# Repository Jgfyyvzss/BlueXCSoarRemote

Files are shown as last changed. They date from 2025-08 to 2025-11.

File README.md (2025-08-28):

# BlueXCSoarRemote
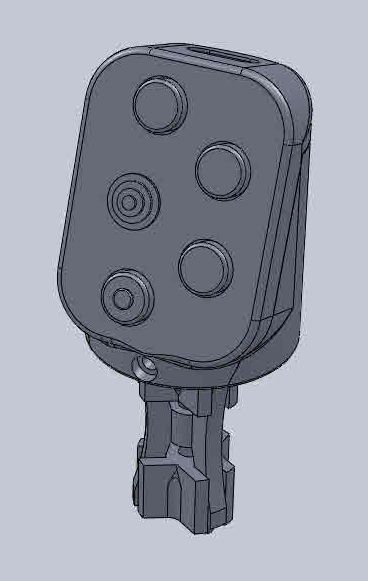
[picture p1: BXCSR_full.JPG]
BlueXCSoarRemote model Cad Model

## Features
A compact Bluetooth remote stick for XCSoar based around an ESP32-C3 Supermini.
* Entirely 3D printed. No need for machined front panels or joystick adapters.
* Sends keystrokes via Bluetooth so only 5V power needs to be supplied to the Remote.
* 5-way navigation joystick
* three top buttons around the joystick
* PTT button at the bottom left.
* On the front of the stick is provision for another two buttons that can be either connected to the remote board or wired direct to other instruments.
* Software is updatable via WiFi or the USB-C port is easily accessible from the top of the stick without any disassembly.

In my setup I use the lower button wired direct to an S100 for Thermal/STF mode switching. The upper button is reserved for future use if I need it.

The keys respond to Click, Double-Click and Long-Press separately, enabling a large number of keystrokes to be sent to XCSoar. In the default cnfiguration the top two buttons use the different clicks, the lower left button is ESC on all three modes.

The head is designed to sit on the top of an existing grip. I don't really like the "ergonomic" control grips, preferring a simple round firm foam grip. I designed this specifically to fit a Galsflugel 19mm dia stick with an ESI Extra Chunky MTB grip on it, but it will likely work OK with many other simple grips.

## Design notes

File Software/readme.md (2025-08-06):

## Key features:
* OTA updates of both Firmware and Keymap file can be done direct from a device to the Remote. The Remote creates an Access Point.
* Keymap can be updated without any change to Firmware. Easily change your button mapping at any time.
* All buttons can have separate actions for Click, Double-Click and Long-Press. Possibility of 24 different keystrokes being sent (only 12 unique keystrokes can be sent at this time).

Currently the following keystrokes can be sent:<br/>
ESC - KEY_ESC<br/>
RETURN - KEY_RETURN<br/>
F1 - KEY_F1<br/>
F2 - KEY_F2<br/>
...<br/>
F10 - KEY_F10<br/>

When the remote first starts (power on) it checks to see if the TopLeft button is being held down. If it is it goes into OTA update mode and starts the Access Point and webserver.<br/>
You will find a WiFi network called BLUEXCREM, password 12345678<br/>
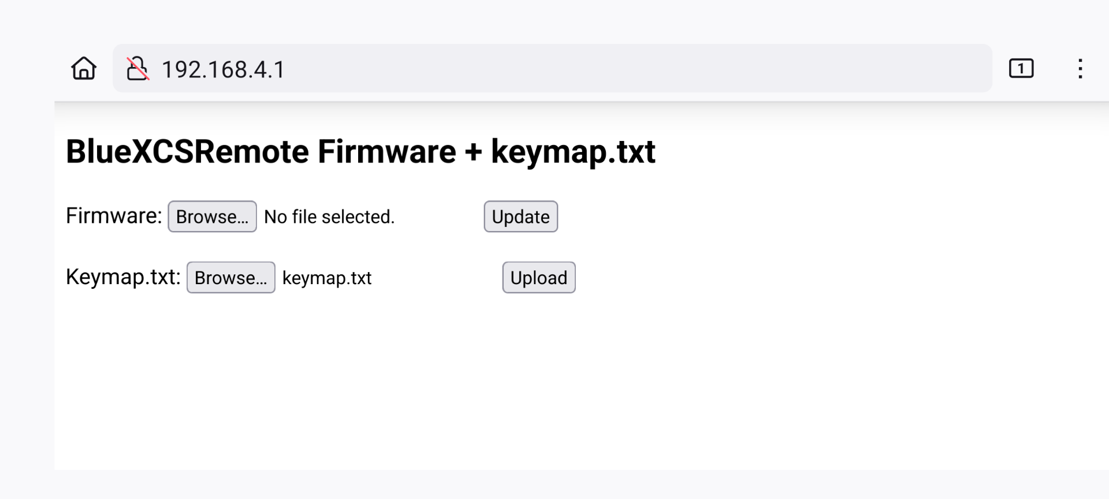
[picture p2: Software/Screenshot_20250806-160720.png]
Once connected to that network you can browse to http://192.168.4.1 (make sure your browser isn't tying to force an https connection) and a page will appear allowing you to select a Firmware ( .bin) or keymap.txt file to /

The keymap.txt file is a simple text file that looks like:<br/>
 \# Click,DoubleClick,LongPress<br/>
Top,KEY_F1,KEY_F3,KEY_F8<br/>
TopRight,KEY_F4,KEY_F5,KEY_F6<br/>
BotRight,KEY_ESC,KEY_ESC,KEY_ESC<br/>
Left,KEY_LEFT_ARROW,,<br/>
Right,KEY_RIGHT_ARROW,,<br/>
Up,KEY_UP_ARROW,,<br/>
Down,KEY_DOWN_ARROW,,<br/>
Centre_Click,KEY_RETURN,,KEY_ESC<br/>

Displaying it as a table makes it easier to understand:<br/>
|# |Click|DoubleClick|LongPress|
|--|-----|---|---|
|Top|KEY_F1|KEY_F3|KEY_F8|
|TopRight|KEY_F4|KEY_F5|KEY_F6|
|BotRight|KEY_ESC|KEY_ESC|KEY_ESC|
|Left|KEY_LEFT_ARROW|||
|Right|KEY_RIGHT_ARROW|||
|Up|KEY_UP_ARROW|||
|Down|KEY_DOWN_ARROW|||
|Centre_Click|KEY_RETURN||KEY_ESC|

The first column is the button name or position.<br/>
Blank cells are ignored.<br/>
Only those keystrokes listed above can be included.<br/>

### Requirements for succesful compilation of the firmware
* Arduino IDE 2+ (created in 2.3.6)
* Arduino IDE esp32 board version 2.0.11. More recent versions will fail to run the BleKeyboard.
* [BleKeyboard library](https://github.com/T-vK/ESP32-BLE-Keyboard) See Note 1.
* [Button2 library](https://github.com/LennartHennigs/Button2)

Note 1: BleKeyboard.cpp has to be modified.<br/>
In your Libraries folder (File | Preferences - Sketchbook Folder) open BleKeyboard.cpp in a plain text editor and find the line:<br/>
pSecurity->setAuthenticationMode(ESP_LE_AUTH_REQ_SC_MITM_BOND);<br/>
Replace this with<br/>
pSecurity->setAuthenticationMode(ESP_LE_AUTH_BOND);<br/>

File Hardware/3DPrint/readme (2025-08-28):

Design of the control head was done in Solidworks 2010.
Slicing via Ultimaker Cura 5.
I printed using a Cocoon Create Touch (Wanhao Duplicator i3 plus)
The screw to retain the faceplate was just scavenged from surplus consumer electronics. Not too critical, just an approximately 2.5mm dia self tapping type screw.

I have included the STL files here for a one-stop-shop, but the full file set will be available at thingiverse.
The front panel should be printed face down with support. The more support the better, but it's a balance between finish quality and being able to remove the support.
The main body is printed standing upright. I've filled the front holes and USB access with a thin web that can easily be cut out if needed to avoid messing with support.
An M3 x 40 socket head screw, nut and washer is used to tighten the Star Plug. Print two Expanders and three StarSingle's.
50% fill seems to produce a good sturdy print, but up to you to experiment.

Retention of the main PCB is by clamping between the two body components, you may need to do some hand finishing of the board to get it to fit and locate correctly.
The front PCB is retained by melting the vertical ribs in a few places. Use an old soldering iron tip or heat up a bit of wire etc. 
Don't go overboard, if you need to remove the PCB you'll need to cut off the melted sections and you'll want to be able to melt new areas when you replace it.

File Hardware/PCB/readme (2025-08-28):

There are two PCB's. BlueXCRemote carrying the Esp32 and main buttons, and FrontButtons carrying the two secondary buttons on the front of the stick.

PCB design was done in Kicad 9.
PCB production was by JLCPCB who accepted the Gerbers with no alterations required.

The front buttons PCB in the first version only has one ground connection. 
This could present a problem if you want to use one button via the ESP32 and the other to control another instrument directly if the other instrument doesn't use battery negative for it's signal ground. Possibly unlikely, but I'll add a second ground pad just in case.

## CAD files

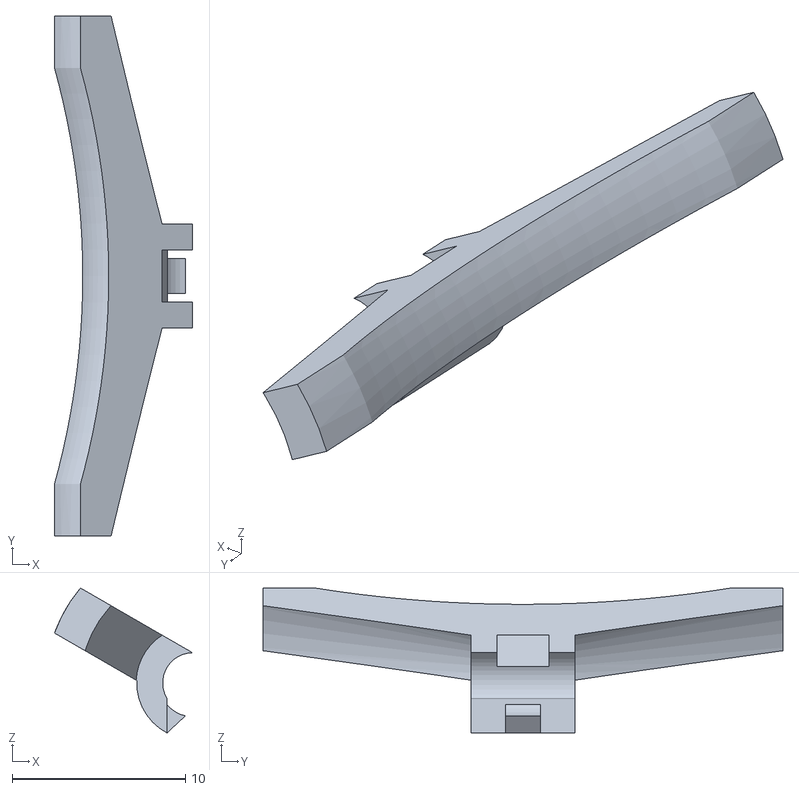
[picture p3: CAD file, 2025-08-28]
Hardware/3DPrint/StarSingle.STL
7.97 x 30.0 x 8.37

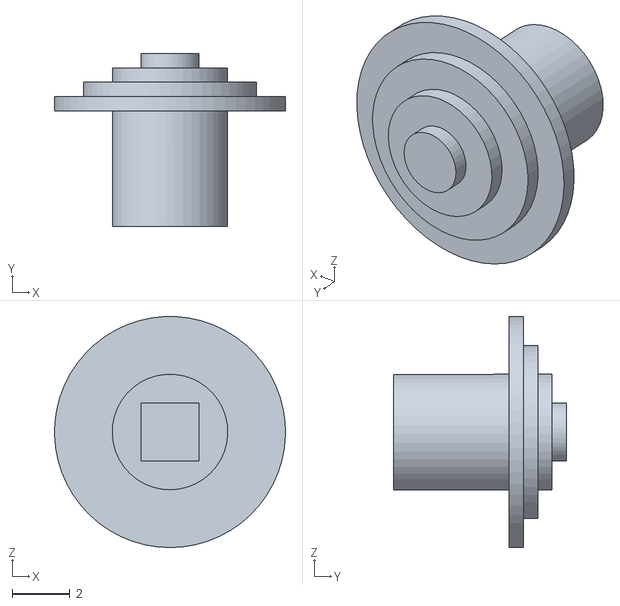
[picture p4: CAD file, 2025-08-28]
Hardware/3DPrint/Joystick.STL
8.00 x 6.00 x 8.00

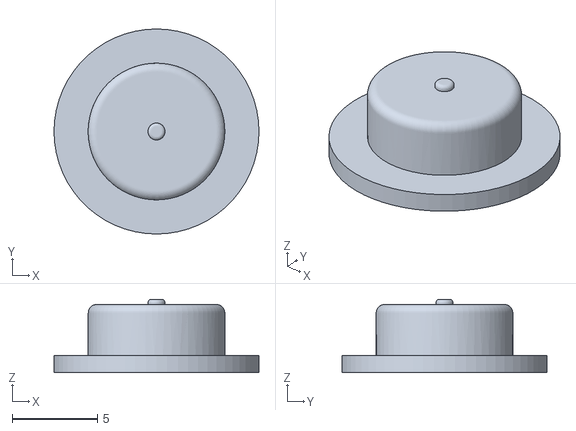
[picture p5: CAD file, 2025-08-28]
Hardware/3DPrint/ButtonR.STL
12.0 x 12.0 x 4.30

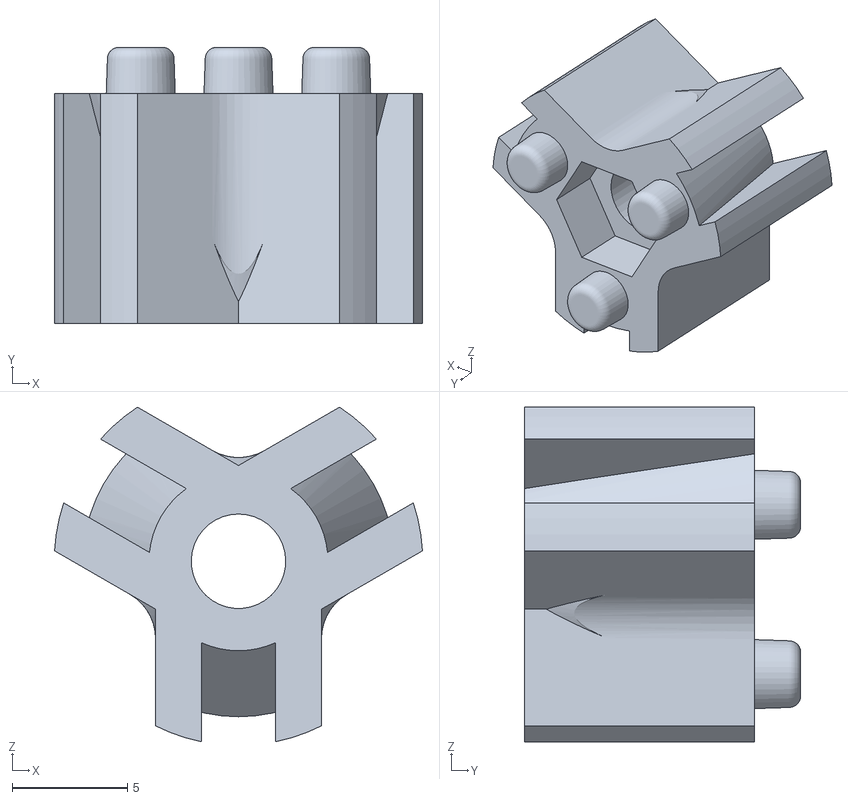
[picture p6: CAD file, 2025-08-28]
Hardware/3DPrint/StarPlugExpander.STL
16.0 x 12.0 x 14.5

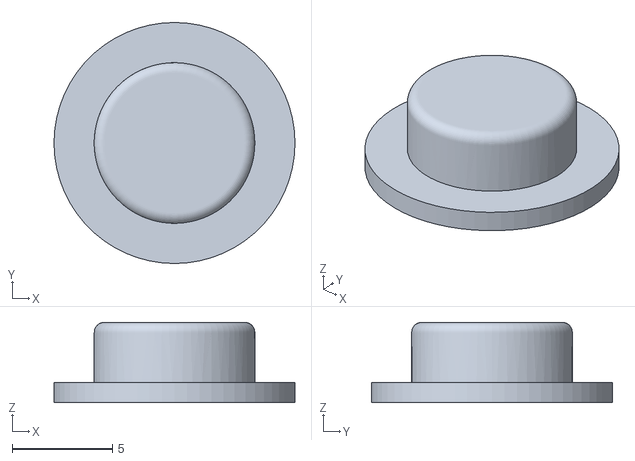
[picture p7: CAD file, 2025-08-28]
Hardware/3DPrint/Button.STL
12.0 x 12.0 x 4.00

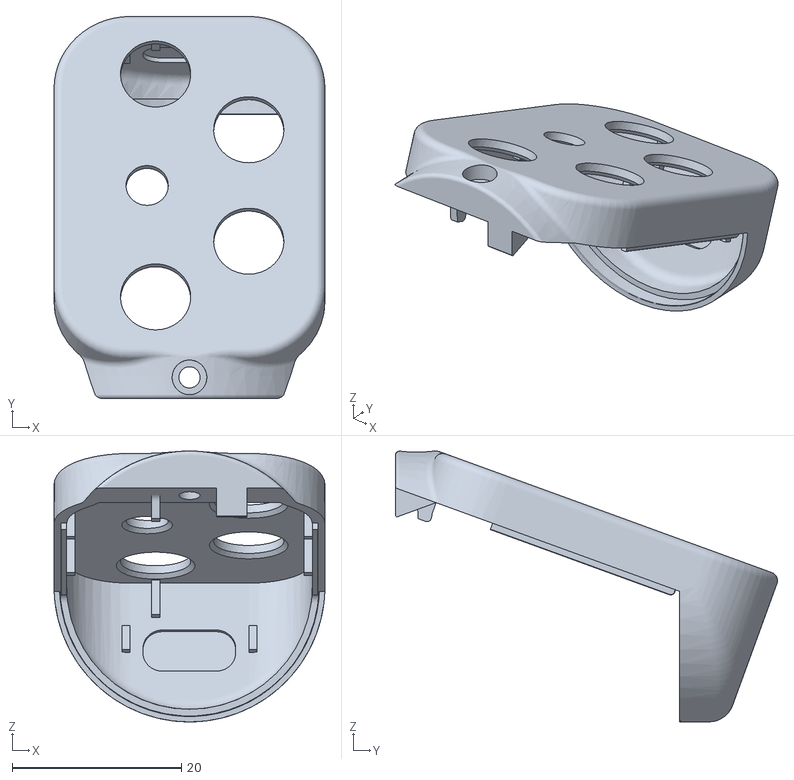
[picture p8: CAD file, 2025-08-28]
Hardware/3DPrint/BR_Body FR.STL
32.0 x 45.1 x 32.0

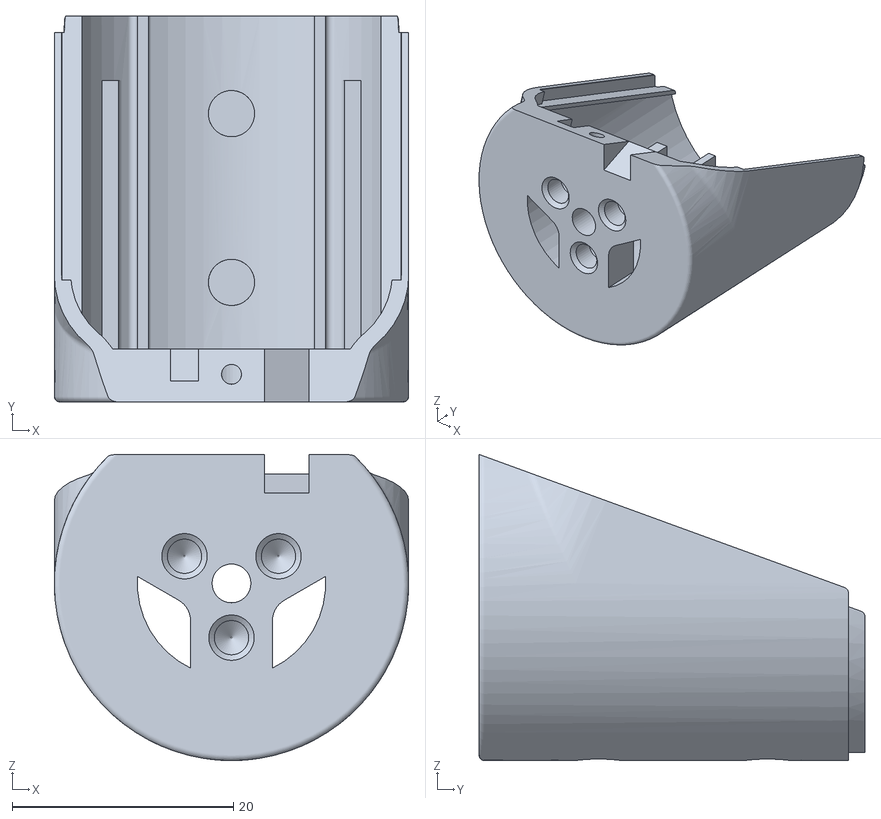
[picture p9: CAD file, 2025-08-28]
Hardware/3DPrint/BR_Body.STL
32.0 x 34.9 x 27.6

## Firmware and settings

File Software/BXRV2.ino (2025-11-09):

// SSID & Pwd at void setupOTA() IP defaults 192.168.4.1
//IO pins defined below #includes
#include <Arduino.h>
#include <Hardware.h>
#include <BleKeyboard.h>
#include <Button2.h>
#include <WiFi.h>
#include <WebServer.h>
#include <Update.h>
#include <LittleFS.h>

#define NUM_BUTTONS 10

BleKeyboard bleKeyboard("BXRKeyboard", "ESP32", 100);
Button2 buttons[NUM_BUTTONS];
// If not using external buttons to XCSoar, decrease count, remove pins, modify data/keymap.txt
// Do not use IO9. Avoid IO2, IO8
// USB on top IO 5, 8, 21, 2, 4, 3, 0, 1, 10, 20
// USB on bottom IO 0, 3, 10, 4, 6, 20, 5, 7, 
const uint8_t buttonPins[NUM_BUTTONS] = {5, 8, 21, 0, 3, 4, 2, 1, 20, 10};

// Button mapping reference:
// Index 0 - Top          = IO pin 5 
// Index 1 - TopRight     = IO pin 8  
// Index 2 - BotRight     = IO pin 21
// Index 3 - Left         = IO pin 0 
// Index 4 - Right        = IO pin 3
// Index 5 - Up           = IO pin 4
// Index 6 - Down         = IO pin 2
// Index 7 - Centre_Click = IO pin 1
// Index 8 - FrTop        = IO pin 20
// Index 9 - FrBot        = IO pin 10 

void handleClick(Button2& btn);
void handleDoubleClick(Button2& btn);
void handleLongClick(Button2& btn);
void loadKeymap();
void sendKey(const String& keyStr);
uint8_t lookupKeyCode(const String& name);

// OTA server
WebServer server(80);
bool otaEnabled = false;

//file upload
File keymapUploadFile;
String uploadBuffer = "";

// OTA HTML Form
void handleRoot() {
  String html = "<!DOCTYPE html>";
  html += "<html><head><title>ESP32C3 Keyboard OTA</title>";
  html += "<style>";
  html += "body { font-family: Arial; margin: 40px; background: #f0f0f0; }";
  html += ".container { background: white; padding: 20px; border-radius: 8px; max-width: 600px; }";
  html += ".upload-section { margin: 20px 0; padding: 15px; border: 1px solid #ddd; border-radius: 4px; }";
  html += "input[type=file] { margin: 10px 0; }";
  html += "button { background: #007cba; color: white; padding: 10px 20px; border: none; border-radius: 4px; cursor: pointer; }";
  html += "button:hover { background: #005a87; }";
  html += "textarea { width: 100%; height: 200px; font-family: monospace; }";
  html += "</style></head><body>";
  html += "<div class=\"container\">";
  html += "<h1>ESP32C3 Keyboard OTA Update</h1>";
  html += "<div class=\"upload-section\">";
  html += "<h3>Firmware Update</h3>";
  html += "<form method='POST' action='/update' enctype='multipart/form-data'>";
  html += "<input type='file' name='update' accept='.bin'>";
  html += "<button type='submit'>Update Firmware</button>";
  html += "</form></div>";
  html += "<div class=\"upload-section\">";
  html += "<h3>Keymap Management</h3>";
  html += "<button onclick=\"downloadKeymap()\">Download Current Keymap</button>";
  html += "<form method='POST' action='/keymap' enctype='multipart/form-data' style=\"margin-top:10px;\">";
  html += "<input type='file' name='keymap' accept='.txt'>";
  html += "<button type='submit'>Upload Keymap</button>";
  html += "</form>";
  html += "<textarea id=\"keymap-display\" readonly></textarea>";
  html += "</div></div>";
  html += "<script>";
  html += "function downloadKeymap() { window.location.href = '/keymap'; }";
  html += "fetch('/keymap').then(r => r.text()).then(d => document.getElementById('keymap-display').value = d);";
  html += "</script></body></html>";
  
  server.send(200, "text/html", html);
}

// OTA 
void handleUpdate() {
  HTTPUpload& upload = server.upload();
  if (upload.status == UPLOAD_FILE_START) {
    Serial.printf("Update: %s\n", upload.filename.c_str());
    if (!Update.begin(UPDATE_SIZE_UNKNOWN)) {
      Update.printError(Serial);
    }
  } else if (upload.status == UPLOAD_FILE_WRITE) {
    if (Update.write(upload.buf, upload.currentSize) != upload.currentSize) {
      Update.printError(Serial);
    }
  } else if (upload.status == UPLOAD_FILE_END) {
    if (Update.end(true)) {
      Serial.printf("Update Success: %u\nRebooting...\n", upload.totalSize);
    } else {
      Update.printError(Serial);
    }
  }
}

void handleUpdateEnd() {
  server.send(200, "text/plain", (Update.hasError()) ? "FAIL" : "OK");
  if (!Update.hasError()) {
    delay(1000);
    ESP.restart();
  }
}

void handleKeymapUpload() {
  Serial.println("DEBUG: handleKeymapUpload called");
  HTTPUpload& upload = server.upload();
  Serial.printf("DEBUG: Upload status = %d\n", upload.status);
  
  if (upload.status == UPLOAD_FILE_START) {
    Serial.printf("DEBUG: Starting upload of %s\n", upload.filename.c_str());
    uploadBuffer = ""; // Clear buffer
  } 
  else if (upload.status == UPLOAD_FILE_WRITE) {
    Serial.printf("DEBUG: Writing %u bytes\n", upload.currentSize);
    // Collect data in buffer
    for (size_t i = 0; i < upload.currentSize; i++) {
      uploadBuffer += (char)upload.buf[i];
    }
    Serial.printf("DEBUG: Buffer now %d bytes\n", uploadBuffer.length());
  } 
  else if (upload.status == UPLOAD_FILE_END) {
    Serial.printf("DEBUG: Upload ended, total buffer: %d bytes\n", uploadBuffer.length());
    Serial.println("DEBUG: Buffer content:");
    Serial.println(uploadBuffer);
  }
}

void handleKeymapUploadEnd() {
  Serial.println("DEBUG: handleKeymapUploadEnd called");
  
  if (uploadBuffer.length() > 0) {
    Serial.println("DEBUG: Writing buffer to file...");
    
    // Write the complete buffer to file
    File file = LittleFS.open("/keymap.txt", "w");
    if (file) {
      size_t written = file.print(uploadBuffer);
      file.close();
      
      Serial.printf("DEBUG: Wrote %u bytes to file\n", written);
      
      // Verify by reading back
      File verifyFile = LittleFS.open("/keymap.txt", "r");
      if (verifyFile) {
        String readBack = verifyFile.readString();
        verifyFile.close();
        Serial.printf("DEBUG: Read back %d bytes\n", readBack.length());
        Serial.println("DEBUG: Read back content:");
        Serial.println(readBack);
        
        loadKeymap(); // Reload keymap
        server.send(200, "text/plain", "Keymap uploaded successfully");
        Serial.println("DEBUG: Success response sent");
      } else {
        Serial.println("DEBUG: Could not verify file");
        server.send(500, "text/plain", "Could not verify upload");
      }
    } else {
      Serial.println("DEBUG: Could not open file for writing");
      server.send(500, "text/plain", "Could not save keymap");
    }
  } else {
    Serial.println("DEBUG: No data in upload buffer");
    server.send(500, "text/plain", "No data received");
  }
  
  uploadBuffer = ""; // Clear buffer
}


void handleKeymapDownload() {
  File file = LittleFS.open("/keymap.txt", "r");
    String content = file.readString();
    file.close();
    server.send(200, "text/plain", content);
}

//START KEYMAP
// Keymap character mapping
struct KeyCodeMap {
  const char* name;
  uint8_t code;
};

const KeyCodeMap keyCodeMap[] = {
  {"KEY_ESC", KEY_ESC},
  {"KEY_RETURN", KEY_RETURN},
  {"KEY_TAB", KEY_TAB},
  {"KEY_BACKSPACE", KEY_BACKSPACE},
  {"KEY_DELETE", KEY_DELETE},
  {"KEY_INSERT", KEY_INSERT},
  {"KEY_HOME", KEY_HOME},
  {"KEY_END", KEY_END},
  {"KEY_PAGE_UP", KEY_PAGE_UP},
  {"KEY_PAGE_DOWN", KEY_PAGE_DOWN},
  {"KEY_UP_ARROW", KEY_UP_ARROW},
  {"KEY_DOWN_ARROW", KEY_DOWN_ARROW},
  {"KEY_LEFT_ARROW", KEY_LEFT_ARROW},
  {"KEY_RIGHT_ARROW", KEY_RIGHT_ARROW},
  {"KEY_F1", KEY_F1},
  {"KEY_F2", KEY_F2},
  {"KEY_F3", KEY_F3},
  {"KEY_F4", KEY_F4},
  {"KEY_F5", KEY_F5},
  {"KEY_F6", KEY_F6},
  {"KEY_F7", KEY_F7},
  {"KEY_F8", KEY_F8},
  {"KEY_F9", KEY_F9},
  {"KEY_F10", KEY_F10},
  {"KEY_F11", KEY_F11},
  {"KEY_F12", KEY_F12}
};

uint8_t lookupKeyCode(const String& name) {
  String trimmedName = name;
  trimmedName.trim();
  
  if (trimmedName.length() == 0) return 0;
  
  if (trimmedName.length() == 1) {
    char ch = trimmedName.charAt(0);
    return (uint8_t)ch;
  }
  
  for (const auto& entry : keyCodeMap) {
    if (trimmedName == entry.name) {
      return entry.code;
    }
  }
  
  Serial.printf("WARNING: Key not found: '%s'\n", trimmedName.c_str());
  return 0;
}

void sendKey(const String& keyStr) {
  if (!bleKeyboard.isConnected()) {
    Serial.println("DEBUG: BLE not connected");
    return;
  }
  
  String trimmed = keyStr;
  trimmed.trim();
  
  if (trimmed.length() == 0) {
    Serial.println("DEBUG: Empty key string, not sending");
    return;
  }
  
  uint8_t code = lookupKeyCode(trimmed);
  if (code > 0) {
    Serial.printf("DEBUG: Sending key '%s' (code: %d)\n", trimmed.c_str(), code);
    bleKeyboard.write(code);
  } else {
    Serial.printf("DEBUG: Key not sent - lookup returned 0 for: '%s'\n", trimmed.c_str());
  }
}

String keymap[NUM_BUTTONS][3];

void handleClick(Button2& btn) {
  int pin = btn.getPin();
  Serial.printf(">>> CLICK on pin %d\n", pin);
  for (int i = 0; i < NUM_BUTTONS; i++) {
    if (buttonPins[i] == pin) {
      Serial.printf("    Button index %d, sending: '%s'\n", i, keymap[i][0].c_str());
      sendKey(keymap[i][0]);
      break;
    }
  }
}

void handleDoubleClick(Button2& btn) {
  int pin = btn.getPin();
  Serial.printf(">>> DOUBLE-CLICK on pin %d\n", pin);
  for (int i = 0; i < NUM_BUTTONS; i++) {
    if (buttonPins[i] == pin) {
      Serial.printf("    Button index %d, sending: '%s'\n", i, keymap[i][1].c_str());
      sendKey(keymap[i][1]);
      break;
    }
  }
}

void handleLongClick(Button2& btn) {
  int pin = btn.getPin();
  Serial.printf(">>> LONG-CLICK on pin %d\n", pin);
  for (int i = 0; i < NUM_BUTTONS; i++) {
    if (buttonPins[i] == pin) {
      Serial.printf("    Button index %d, sending: '%s'\n", i, keymap[i][2].c_str());
      sendKey(keymap[i][2]);
      break;
    }
  }
}

void loadKeymap() {
  Serial.println("========================================");
  Serial.println("Loading keymap from /keymap.txt...");
  Serial.println("========================================");
  
  File file = LittleFS.open("/keymap.txt", "r");
  if (!file) {
    Serial.println("ERROR: Failed to open keymap.txt");
    return;
  }
  
  int i = 0;
  int lineNum = 0;
  
  while (file.available() && i < NUM_BUTTONS) {
    String line = file.readStringUntil('\n');
    lineNum++;
    line.trim();
    
    if (line.length() == 0 || line.startsWith("#")) {
      Serial.printf("Line %d: Skipped (comment/empty)\n", lineNum);
      continue;
    }

    Serial.printf("Line %d: %s\n", lineNum, line.c_str());

    int idx0 = line.indexOf(',');
    int idx1 = line.indexOf(',', idx0 + 1);
    int idx2 = line.indexOf(',', idx1 + 1);

    if (idx0 == -1 || idx1 == -1 || idx2 == -1) {
      Serial.printf("  ERROR: Invalid format (missing commas)\n");
      continue;
    }

    keymap[i][0] = line.substring(idx0 + 1, idx1);
    keymap[i][1] = line.substring(idx1 + 1, idx2);
    keymap[i][2] = line.substring(idx2 + 1);
    
    keymap[i][0].trim();
    keymap[i][1].trim();
    keymap[i][2].trim();

    Serial.printf("  -> Button %d (IO Pin %d):\n", i, buttonPins[i]);
    Serial.printf("     Click:  '%s'\n", keymap[i][0].c_str());
    Serial.printf("     Double: '%s'\n", keymap[i][1].c_str());
    Serial.printf("     Long:   '%s'\n", keymap[i][2].c_str());
    
    i++;
  }

  file.close();
  Serial.println("========================================");
  Serial.printf("Keymap loaded: %d buttons configured\n", i);
  Serial.println("========================================");
}
// END KEYMAP

// OTA Server setup
void setupOTA() {
  Serial.println("DEBUG: setupOTA starting...");
  
  WiFi.mode(WIFI_AP);
  WiFi.softAP("BXRemote", "12345678");
  
  Serial.println("OTA Access Point started");
  Serial.print("IP address: ");
  Serial.println(WiFi.softAPIP());

  // Register handlers
  server.on("/", HTTP_GET, handleRoot);
  server.on("/update", HTTP_POST, handleUpdateEnd, handleUpdate);
  
  // Register keymap handlers - use separate paths for clarity
  server.on("/keymap", HTTP_GET, handleKeymapDownload);
  server.on("/keymap", HTTP_POST, handleKeymapUploadEnd, handleKeymapUpload);
  
  // Add debug handler to test server is working
  server.on("/test", HTTP_GET, []() {
    Serial.println("DEBUG: /test endpoint called");
    server.send(200, "text/plain", "Server is working!");
  });
  
  server.onNotFound([]() {
    Serial.printf("DEBUG: Unknown request: %s %s\n", 
                  server.method() == HTTP_GET ? "GET" : "POST", 
                  server.uri().c_str());
    server.send(404, "text/plain", "Not Found");
  });
  
  server.begin();
  Serial.println("DEBUG: OTA server started");
}

//Setup
void setup() {
  // Initialize Serial FIRST - before any other code
  Serial.begin(115200);
  delay(1000);  // Give Serial time to initialize
  Serial.println("=== ESP32C3 Keyboard Starting ===");
  
  pinMode(buttonPins[0], INPUT_PULLUP);
  delay(100);  // Allow time for button detection
  otaEnabled = digitalRead(buttonPins[0]) == LOW;
  
  Serial.printf("OTA Mode: %s\n", otaEnabled ? "ENABLED" : "DISABLED");

  if (otaEnabled) {
    Serial.println("Starting OTA mode...");
    setCpuFrequencyMhz(160);
    
    WiFi.mode(WIFI_AP);
    WiFi.softAP("BLUEXCREM", "12345678");  // Your original SSID/PWD
    delay(500);
    
    Serial.println("WiFi AP started");
    Serial.print("IP address: ");
    Serial.println(WiFi.softAPIP());
    
    // Initialize LittleFS with detailed logging
    Serial.println("Initializing LittleFS...");
    if (!LittleFS.begin(true)) {
      Serial.println("LittleFS initialization failed! Trying format...");
      if (!LittleFS.format()) {
        Serial.println("LittleFS format failed!");
      } else {
        Serial.println("LittleFS formatted successfully");
        if (!LittleFS.begin(false)) {
          Serial.println("LittleFS still failed after format!");
        } else {
          Serial.println("LittleFS initialized after format");
        }
      }
    } else {
      Serial.println("LittleFS initialized successfully");
      Serial.printf("Total: %u bytes, Used: %u bytes\n", 
                    LittleFS.totalBytes(), LittleFS.usedBytes());
    }
    
    // Test if keymap file exists
    if (LittleFS.exists("/keymap.txt")) {
      File testFile = LittleFS.open("/keymap.txt", "r");
      if (testFile) {
        Serial.printf("Existing keymap file size: %u bytes\n", testFile.size());
        testFile.close();
      }
    } else {
      Serial.println("No existing keymap file found");
    }
    
    setupOTA();
  } else {
    Serial.println("Starting BLE keyboard mode...");
    setCpuFrequencyMhz(80);
    
    Serial.println("Initializing LittleFS for BLE mode...");
    LittleFS.begin(false);
    
    Serial.println("Starting BLE keyboard...");
    bleKeyboard.begin();
    
    Serial.println("Loading keymap...");
    loadKeymap();
    
    Serial.println("Setting up buttons...");
      for (int i = 0; i < NUM_BUTTONS; i++) {
        buttons[i].begin(buttonPins[i]);
        buttons[i].setLongClickTime(800);
        buttons[i].setClickHandler(handleClick);
        buttons[i].setDoubleClickHandler(handleDoubleClick);
        buttons[i].setLongClickDetectedHandler(handleLongClick);  // Immediate trigger
    }
    Serial.println("BLE keyboard setup complete");
  }
  
  Serial.println("=== Setup Complete ===");
}

void loop() {
  if (otaEnabled) {
    server.handleClient();
    delay(10);
  } else {
    for (int i = 0; i < NUM_BUTTONS; i++) {
      buttons[i].loop();
    }
  }
  delay(10);
}

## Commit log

2025-08-05 Create Electronics BOM
2025-08-05 Initial Electronics BOM
2025-08-05 Update Electronics BOM
2025-08-28 Add files via upload
    Initial versions. Buttons and StarPlugExpander still need revision.
    [BR_Body FR.STL, BR_Body.STL, Button.STL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]
2025-11-09 keymap V2
    Keymap with front buttons defined
    File with standard XCSoar default key shortcuts
